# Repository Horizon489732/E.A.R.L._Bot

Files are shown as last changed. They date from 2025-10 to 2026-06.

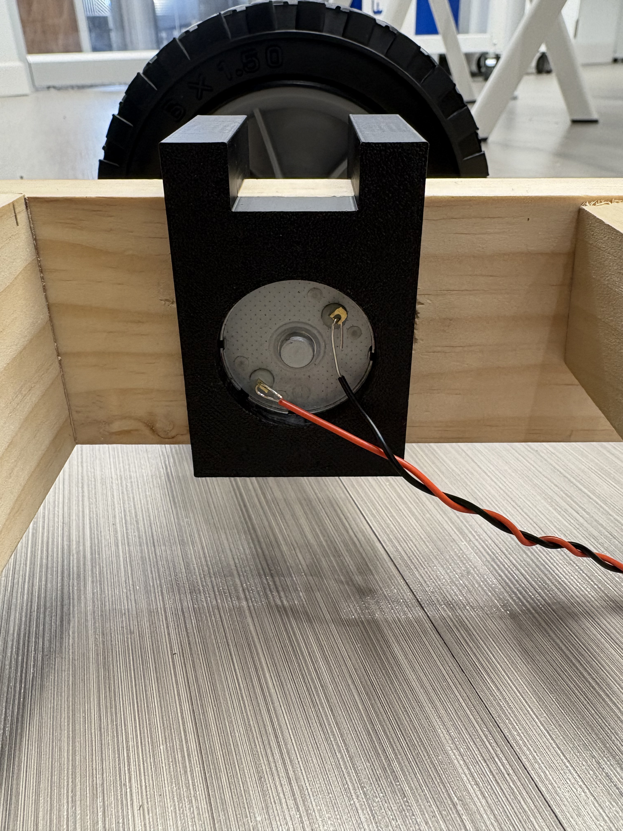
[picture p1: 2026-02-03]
Documentation/IMG_0114.jpeg

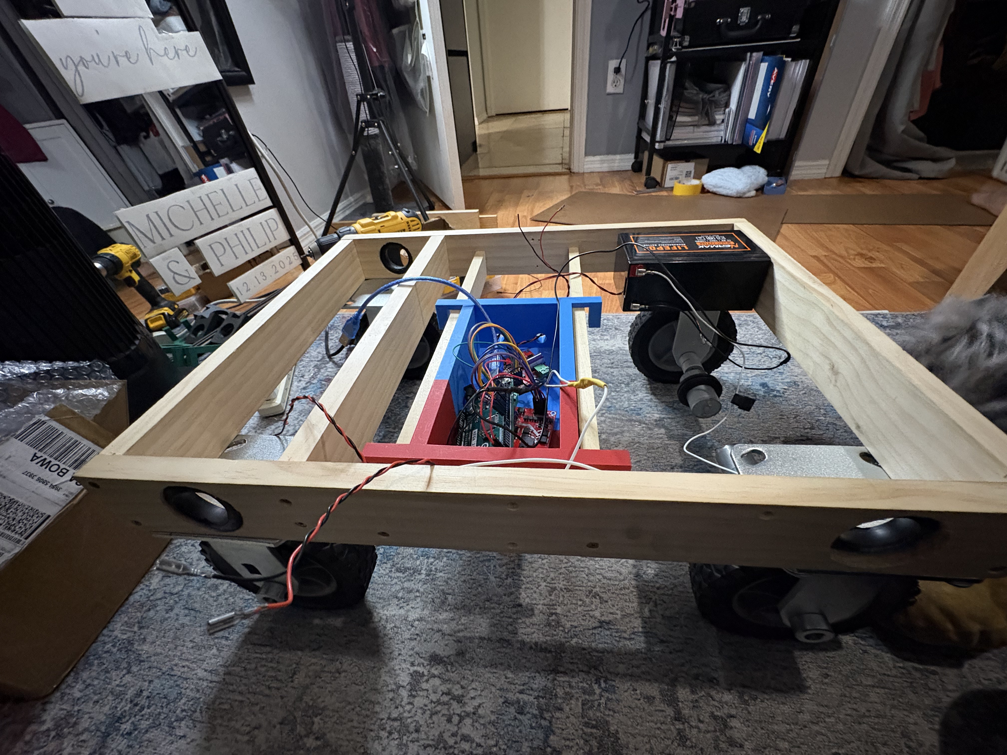
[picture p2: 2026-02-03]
Documentation/IMG_0233.jpeg

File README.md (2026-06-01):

# Everywhere-Anytime-Ready-for-Loading-BOT
- E.A.R.L. Bot will be a personal autonomous assistant ready to help you carry your items. E.A.R.L. Bot will be able to follow you around using tracking modules and sensors, helping students carry things around campus!

## Team Members & Roles
- Michelle Lee
- Daniel Jaffe
- Hien Tran
- Chris Nucci

Team EARL

## Demo

https://github.com/user-attachments/assets/fcbea098-207b-40ab-b3ea-2b303ecb1e78

## Object Detection

https://github.com/user-attachments/assets/0ccd8ff6-e306-4a9d-9102-31fed9cfe05f

## Technologies
- Microcontroller: An Arduino board will serve as the main processing unit, handling sensor data,
motor control, and communication with the tracking system.
- User Tracking: The robot will use RFID, Bluetooth Low Energy (BLE) beacons, or UltraWideband (UWB) technology to detect and follow a card or tag carried by the user. These technologies
allow accurate real-time positioning of the user even in busy environments.
- Receiver Modules: A corresponding RFID reader, BLE receiver, or UWB receiver on the robot
will process the signals from the user’s tag to determine distance and direction.
- Obstacle Detection and Avoidance: Ultrasonic sensors will scan the robot’s surroundings to detect
obstacles and navigate around them safely. Optional infrared (IR) sensors or LIDAR could be added
for higher accuracy in complex environments.
- Motion Control: Motor drivers will control the wheels, enabling smooth acceleration, deceleration,
and turning. Wheel encoders may be used for precise speed and distance measurement.
- Power Supply and Battery Management: A rechargeable battery will power the robot, and a
battery management system will ensure safe and efficient energy usage. 

## Goals
# Semester 1: Minimum Viable Product (MVP)
Autonomous User Tracking: Develop and implement a reliable sensor-based tracking system allowing the robot to seamlessly follow a designated target tag.

Payload Transport Capacity: Design and construct a rugged chassis capable of securely housing and transporting student items (such as backpacks and textbooks) across flat surfaces.

# Semester 2: Advanced Features & Refinement
Dynamic Obstacle Avoidance: Integrate ultrasonic sensors with real-time navigation algorithms to safely detect, slow down, and steer around obstacles or pedestrians in busy campus environments.

Aesthetics & Custom Branding: Complete the physical build by applying a clean paint job, enclosing the electronics safely, and mounting a custom, stylized E.A.R.L. signature sign to give the assistant a polished, professional look.

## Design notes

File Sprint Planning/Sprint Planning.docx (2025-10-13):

# E.A.R.L. Bot

E.A.R.L.

Chris Nucci, Daniel Jaffe, Hien Tran, Michelle Lee

GitHub repository:

Trello board: https://trello.com/b/Lrr7T9cK/earl-bot

# Sprint 1

Sprint Goal: Build E.A.R.L. Bot’s frame, mount the motors and wheels, and make the bot move back and forth.

Tasks:

Task | Team Member | Effort Estimation | Dependencies/Blockers | Task Breakdown
Design Frame | Michelle/ Hien/ Chris/ Daniel | 1 hour | NA | NA
Build Frame | Michelle | 1 hour | Wait till all parts for frame are attained. | NA
Mount Motors | Michelle | <1 hour | | NA
Mount/ Connect Wheels | Chris / Hien | 30 minutes | Frame needs to be done first | NA
Power Motors | Daniel / Hien | 1 hour | Motors need to be mounted with wheels first | NA
Program Arduino to Move in Sync | Daniel | 2 hours | NA | NA
Implement Power Switch | Daniel / Michelle | 1 hour | NA | NA

# Sprint 2

Sprint Goal: E.A.R.L. has a cargo hold and is able to do very simple tracking and following

Tasks Planned:

- Finish leftover tasks from Sprint 1
- Implement simple tracking
- Build Tag housing
- Build side rails for cargo area

# Sprint 3

Sprint Goal: E.A.R.L. is able to adjust speed based off distance to user.

Tasks Planned:

- Optimize distance and speed control
- Work out any bugs
- Aesthetic modifications

# Trello board

Entire Trello Board

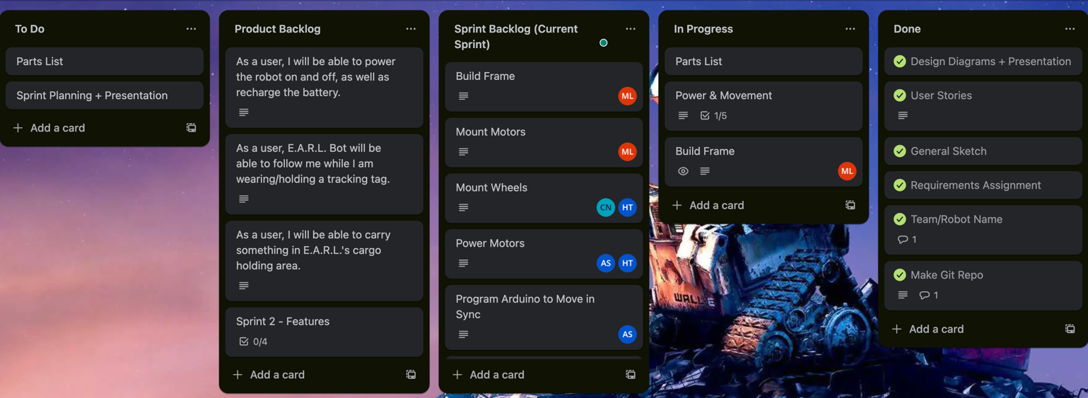
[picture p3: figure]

Product and Sprint Backlogs

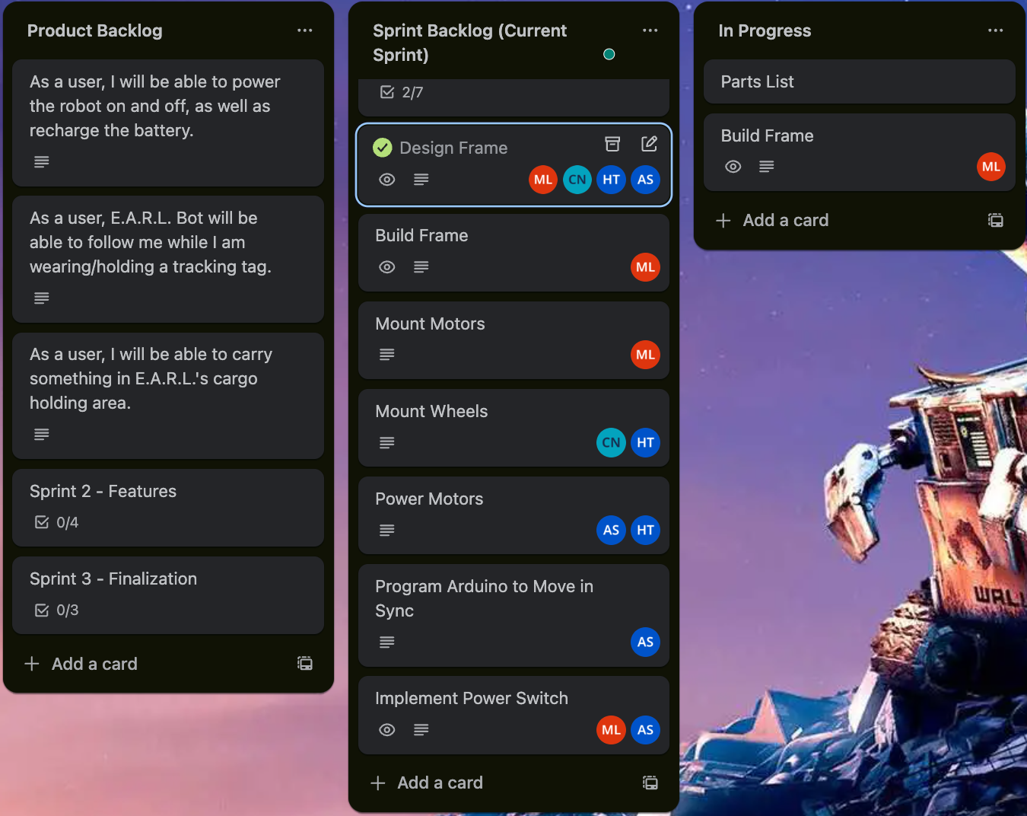
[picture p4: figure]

Close up of 1 task on Sprint Backlog – all other looks similar with their own times and dependencies

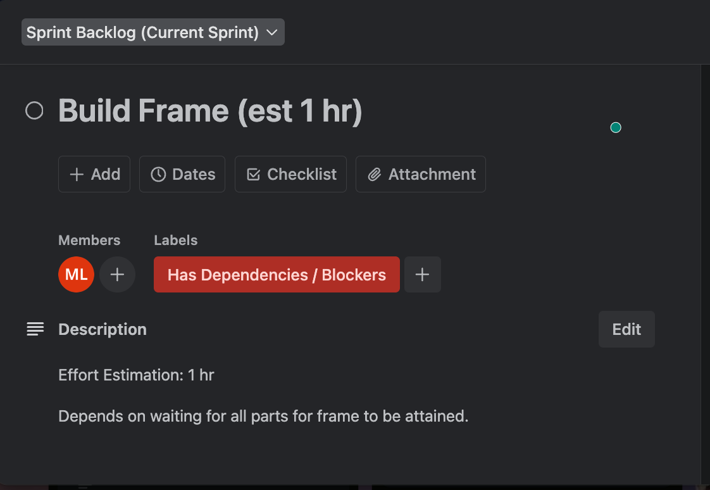
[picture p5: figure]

Senior Capstone I

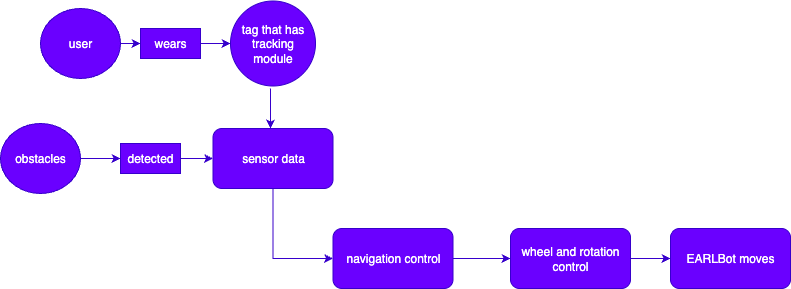
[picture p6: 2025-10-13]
Design Diagrams/Data_Flow_Diagram.png

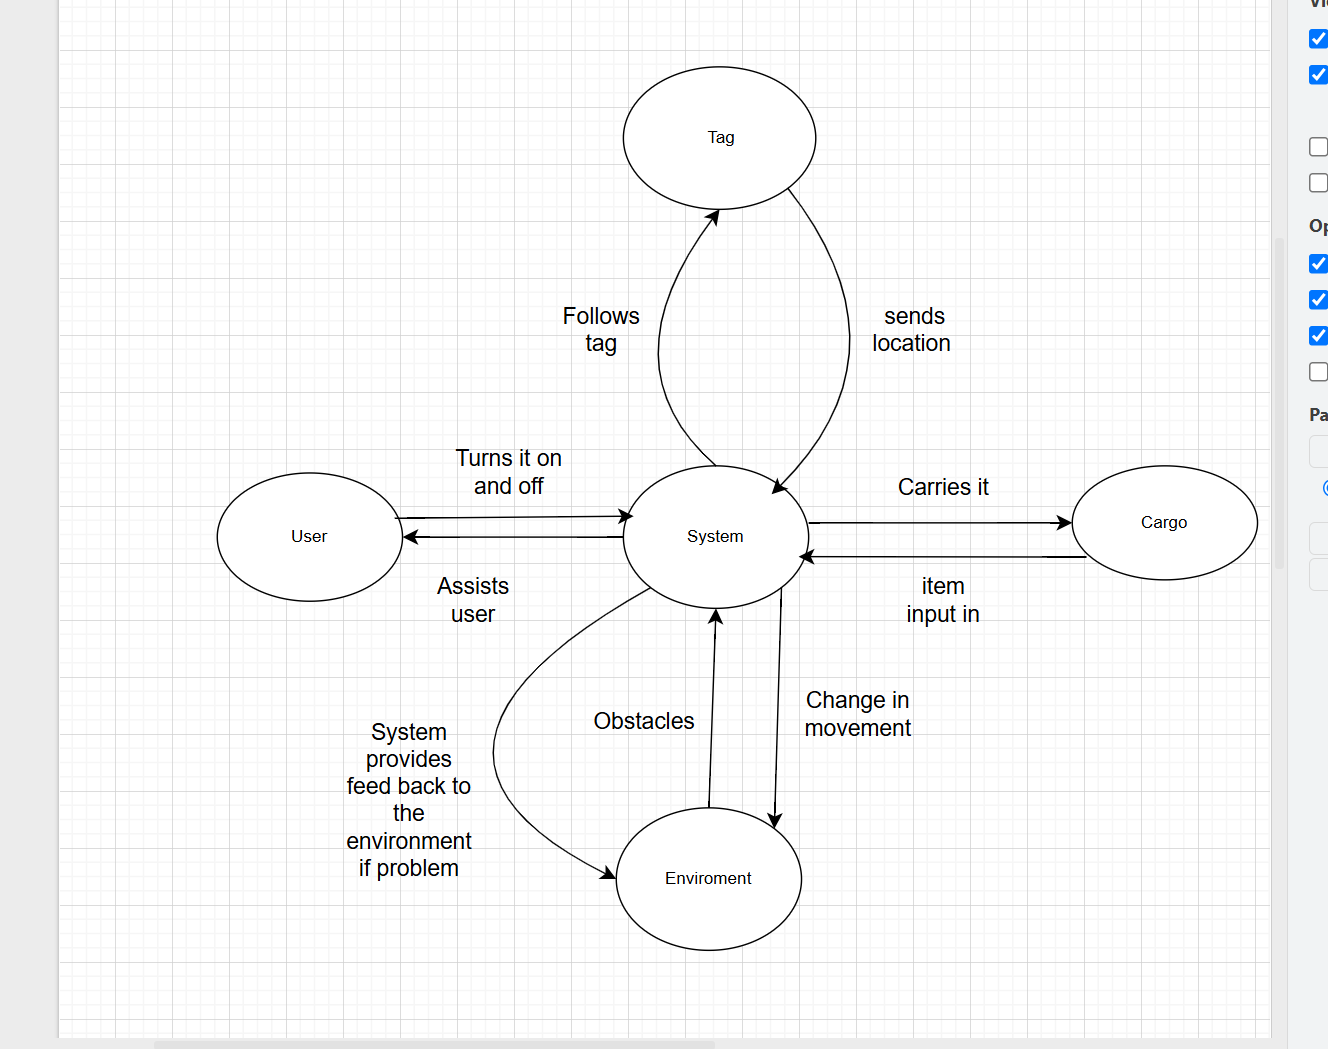
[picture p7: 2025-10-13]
Design Diagrams/context.png

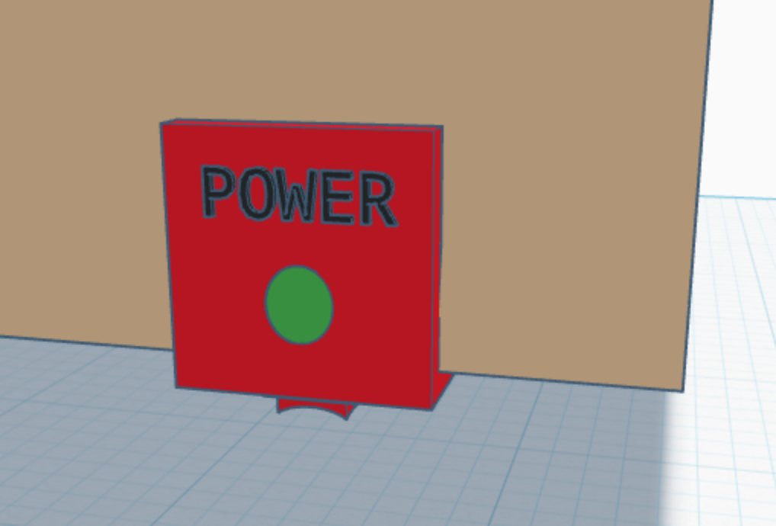
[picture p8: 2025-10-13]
Design Diagrams/UI Mockups/Screenshot 2025-10-05 at 12.27.10 AM.png

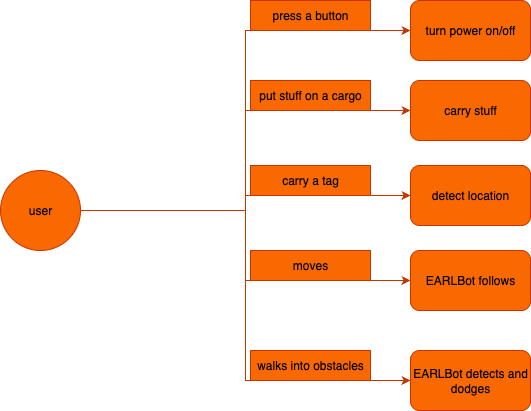
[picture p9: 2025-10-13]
Design Diagrams/Use_Case_Diagram.png

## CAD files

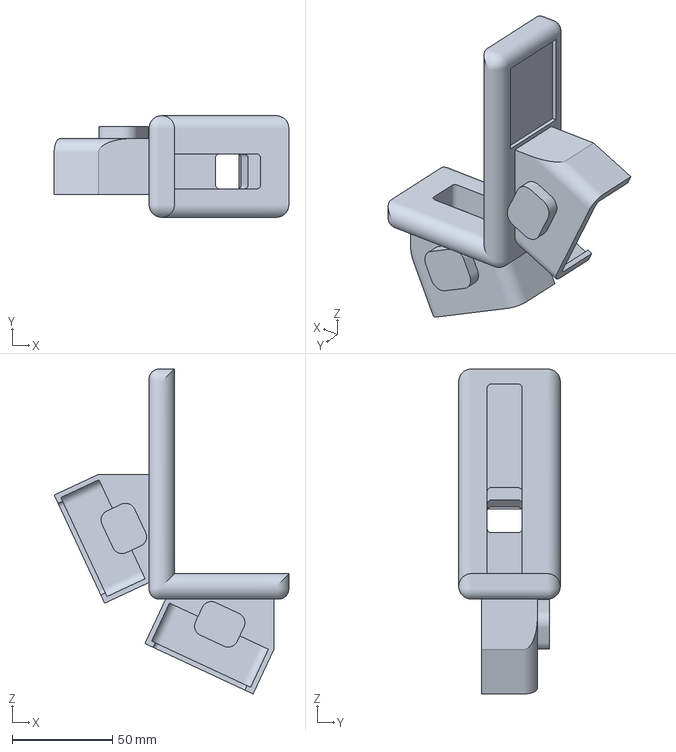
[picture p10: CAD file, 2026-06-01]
modeling Designs/assembly for ultrasonic sensors.3mf
117.3 x 50.8 x 162.4 mm

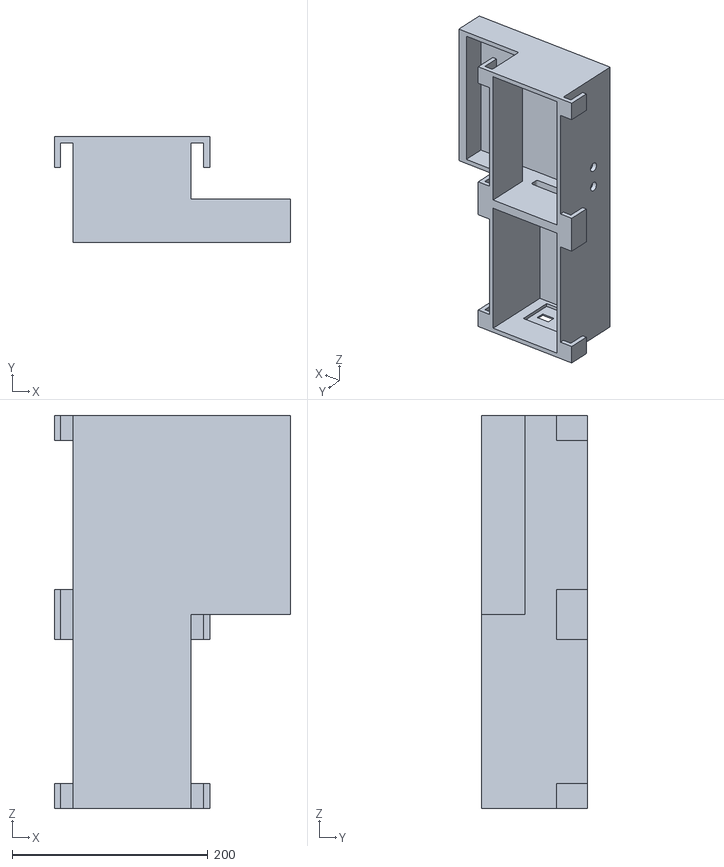
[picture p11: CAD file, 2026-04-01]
modeling Designs/basket for arduino.stl
241.3 x 107.9 x 401.3

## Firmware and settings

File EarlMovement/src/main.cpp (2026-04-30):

#include <Arduino.h>
#include <FastLED.h>

#define NUM_LEDS 7
#define DATA_PIN 13
#define BRIGHTNESS 255

CRGB leds[NUM_LEDS];

// Left Front Motor
int L_IN1 = 6;
int L_IN2 = 5;
int L_ENA = 7;

// Right Front Motor
int R_IN1 = 8;
int R_IN2 = 9;
int R_ENA = 10;

// Default speed (0–255)
int speed = 255;

int lastTimeReceived = 0;
int timeout = 5000;
// for distance reading
String incoming = "";

// for calculating connection timing
unsigned long startTime;
const int DATA_TIMEOUT_MS = 500;

// ===================== HC-SR04 SETUP =====================
// Current sensors (you already have these)
const int L_TRIG_PIN = 11;   // LEFT FRONT
const int L_ECHO_PIN = 12;

const int R_TRIG_PIN = 2;    // RIGHT FRONT
const int R_ECHO_PIN = 3;

// NEW sensors (CHANGE THESE PINS TO MATCH YOUR WIRING)
const int L2_TRIG_PIN = 47;   // LEFT SIDE (new)
const int L2_ECHO_PIN = 46;

const int R2_TRIG_PIN = 45;  // RIGHT SIDE (new)  <-- change if you want
const int R2_ECHO_PIN = 44;  // RIGHT SIDE (new)  <-- change if you want

float leftTiming = 0.0;
float leftDistanceCm = 0.0;
float rightTiming = 0.0;
float rightDistanceCm = 0.0;

float left2Timing = 0.0;
float left2DistanceCm = 0.0;
float right2Timing = 0.0;
float right2DistanceCm = 0.0;

// Anchor distances
struct AnchorDistances {
  int anchor1 = 0;
  int anchor2 = 0;
  int anchor3 = 0;
};

AnchorDistances dist;

// ===================== Avoidance settings/state =====================
const int AVOID_CM = 30;        // object avoidance threshold
const int DOORWAY_CM = 20;      // doorway override threshold

int avoidSide = 0;              // 0 = none, 1 = avoiding LEFT side, 2 = avoiding RIGHT side
int avoidSensor = 0;            // 1 = front sensor triggered, 2 = side sensor triggered
bool avoidPrinted = false;      // print message once when starting avoidance

// ===================== Helper: Stop all motors =====================
void stopMotors() {
  analogWrite(L_ENA, 0);
  analogWrite(R_ENA, 0);

  digitalWrite(R_IN1, LOW);
  digitalWrite(R_IN2, LOW);
  digitalWrite(L_IN1, LOW);
  digitalWrite(L_IN2, LOW);
}

// ===================== Move Forward =====================
void forward(int spd) {
  analogWrite(R_ENA, spd * 0.8);
  analogWrite(L_ENA, spd );

  digitalWrite(R_IN1, HIGH);
  digitalWrite(R_IN2, LOW);

  digitalWrite(L_IN1, HIGH);
  digitalWrite(L_IN2, LOW);
}

// ===================== Move Backward =====================
void backward(int spd) {
  analogWrite(R_ENA, spd);
  analogWrite(L_ENA, spd);

  digitalWrite(R_IN1, LOW);
  digitalWrite(R_IN2, HIGH);

  digitalWrite(L_IN1, LOW);
  digitalWrite(L_IN2, HIGH);
}

void moveAndTurnLeft2(int spd, int percentSpd) {
  analogWrite(R_ENA, spd);
  analogWrite(L_ENA, spd * (percentSpd / 100.0));

  digitalWrite(R_IN1, HIGH);
  digitalWrite(R_IN2, LOW);
  digitalWrite(L_IN1, HIGH);
  digitalWrite(L_IN2, LOW);
}

void moveAndTurnRight2(int spd, int percentSpd) {
  analogWrite(L_ENA, spd);
  analogWrite(R_ENA, spd * (percentSpd / 100.0));

  digitalWrite(R_IN1, HIGH);
  digitalWrite(R_IN2, LOW);
  digitalWrite(L_IN1, HIGH);
  digitalWrite(L_IN2, LOW);
}

// ===================== SERIAL PARSING =====================
void parseAnchorDistance(String line){
  int anchorID = 0;
  int anchorPos = line.indexOf("Anchor ");
  int dashPos   = line.indexOf(" -");
  if (anchorPos != -1 && dashPos != -1) {
      String idStr = line.substring(anchorPos + 7, dashPos);
      anchorID = idStr.toInt();
  }

  int colonIndex = line.indexOf(": ");
  int distance = 0;
  if (colonIndex != -1) {
      String distanceStr = line.substring(colonIndex + 2);
      int spaceIndex = distanceStr.indexOf(" ");
      if (spaceIndex != -1) {
          distanceStr = distanceStr.substring(0, spaceIndex);
      }
      distance = distanceStr.toInt();
  }

  switch(anchorID) {
      case 1: dist.anchor1 = distance; break;
      case 2: dist.anchor2 = distance; break;
      case 3: dist.anchor3 = distance; break;
  }
}

// ===================== Ultrasonic reads =====================

// LEFT FRONT
float readLeftUltrasonicCm() {
  digitalWrite(L_TRIG_PIN, LOW);
  delayMicroseconds(5);

  digitalWrite(L_TRIG_PIN, HIGH);
  delayMicroseconds(10);
  digitalWrite(L_TRIG_PIN, LOW);

  leftTiming = pulseIn(L_ECHO_PIN, HIGH, 30000);
  if (leftTiming == 0) return 0;
  return (leftTiming * 0.0344) / 2.0;
}

// RIGHT FRONT
float readRightUltrasonicCm() {
  digitalWrite(R_TRIG_PIN, LOW);
  delayMicroseconds(5);

  digitalWrite(R_TRIG_PIN, HIGH);
  delayMicroseconds(10);
  digitalWrite(R_TRIG_PIN, LOW);

  rightTiming = pulseIn(R_ECHO_PIN, HIGH, 30000);
  if (rightTiming == 0) return 0;
  return (rightTiming * 0.0344) / 2.0;
}

// LEFT SIDE (new)
float readLeft2UltrasonicCm() {
  digitalWrite(L2_TRIG_PIN, LOW);
  delayMicroseconds(5);

  digitalWrite(L2_TRIG_PIN, HIGH);
  delayMicroseconds(10);
  digitalWrite(L2_TRIG_PIN, LOW);

  left2Timing = pulseIn(L2_ECHO_PIN, HIGH, 30000);
  if (left2Timing == 0) return 0;
  return (left2Timing * 0.0344) / 2.0;
}

// RIGHT SIDE (new)
float readRight2UltrasonicCm() {
  digitalWrite(R2_TRIG_PIN, LOW);
  delayMicroseconds(5);

  digitalWrite(R2_TRIG_PIN, HIGH);
  delayMicroseconds(10);
  digitalWrite(R2_TRIG_PIN, LOW);

  right2Timing = pulseIn(R2_ECHO_PIN, HIGH, 30000);
  if (right2Timing == 0) return 0;
  return (right2Timing * 0.0344) / 2.0;
}

void calculateDirection() {

  // =============================
  // If we're already avoiding a side,
  // keep turning until BOTH sensors on that side are clear.
  // While doing this, ignore everything else.
  // =============================
  if (avoidSide == 1) { // avoiding LEFT side -> turn RIGHT
    bool leftBlocked = (leftDistanceCm > 0 && leftDistanceCm <= AVOID_CM);
    bool left2Blocked = (left2DistanceCm > 0 && left2DistanceCm <= AVOID_CM);

    if (leftBlocked || left2Blocked) {
      if (!avoidPrinted) {
        Serial.print("Avoiding LEFT side (trigger sensor ");
        Serial.print(avoidSensor);
        Serial.println(") -> turning RIGHT until clear");
        avoidPrinted = true;
      }
      moveAndTurnRight2(speed, 0);
      return;
    } else {
      Serial.println("LEFT side clear -> stopping avoidance");
      avoidSide = 0;
      avoidSensor = 0;
      avoidPrinted = false;
      // fall through to normal logic
    }
  }

  if (avoidSide == 2) { // avoiding RIGHT side -> turn LEFT
    bool rightBlocked = (rightDistanceCm > 0 && rightDistanceCm <= AVOID_CM);
    bool right2Blocked = (right2DistanceCm > 0 && right2DistanceCm <= AVOID_CM);

    if (rightBlocked || right2Blocked) {
      if (!avoidPrinted) {
        Serial.print("Avoiding RIGHT side (trigger sensor ");
        Serial.print(avoidSensor);
        Serial.println(") -> turning LEFT until clear");
        avoidPrinted = true;
      }
      moveAndTurnLeft2(speed, 20);
      return;
    } else {
      Serial.println("RIGHT side clear -> stopping avoidance");
      avoidSide = 0;
      avoidSensor = 0;
      avoidPrinted = false;
      // fall through to normal logic
    }
  }

  // =============================
  // 1️⃣ Check if tag disconnected
  // =============================
  if (dist.anchor1 == -1 || dist.anchor1 == 65535 ||
      dist.anchor2 == -1 || dist.anchor2 == 65535 ||
      dist.anchor3 == -1 || dist.anchor3 == 65535) {

    Serial.println("Stop Moving - tag disconnected");
    stopMotors();
    return;
  }

  // =============================
  // 2️⃣ Make sure anchors valid
  // =============================
  if (dist.anchor1 <= 30 || dist.anchor2 <= 30) {
    Serial.println("Invalid small reading");
    stopMotors();
    return;
  }

  // =============================
  // 3️⃣ Stop if too close
  // =============================
  if (dist.anchor1 < 175 || dist.anchor2 < 175) {
    Serial.println("Stopping Motors - too close");
    stopMotors();
    return;
  }

  // =============================
  // 4️⃣ Stop if too far
  // =============================
  if (dist.anchor1 > 1000 || dist.anchor2 > 1000) {
    Serial.println("Stopping Motors - too far");
    stopMotors();
    return;
  }


  // =============================
  // 4️⃣ Wrong direction check
  // =============================
  if (dist.anchor3 > dist.anchor1 && dist.anchor3 > dist.anchor2) {

    Serial.println("Wrong direction - pivot");

    if (dist.anchor1 > dist.anchor2) {
      Serial.println("Pivot Right");
      moveAndTurnRight2(speed, 0);
    } else {
      Serial.println("Pivot Left");
      moveAndTurnLeft2(speed, 0);
    }

    return;
  }

  // =============================
  // Doorway balancing override (front sensors only)
  // =============================
  if (leftDistanceCm > 0 && rightDistanceCm > 0 &&
      leftDistanceCm <= DOORWAY_CM && rightDistanceCm <= DOORWAY_CM) {

    Serial.println("Doorway balancing: BOTH <= 20cm -> going straight");
    forward(speed);
    return;
  }

  // =============================
  // NEW: Side avoidance start
  // If ONE sensor on a side sees something, start turning away.
  // Ignore the other sensor for "choosing" what to do (no flip-flopping),
  // but require BOTH sensors on that side to clear to stop turning.
  // =============================

  // LEFT side triggers -> start avoiding LEFT side (turn RIGHT)
  if (leftDistanceCm > 0 && leftDistanceCm <= AVOID_CM) {
    avoidSide = 1;
    avoidSensor = 1;   // front left triggered
    avoidPrinted = false;
    moveAndTurnRight2(speed, 0);
    return;
  }
  if (left2DistanceCm > 0 && left2DistanceCm <= AVOID_CM) {
    avoidSide = 1;
    avoidSensor = 2;   // side left triggered
    avoidPrinted = false;
    moveAndTurnRight2(speed, 0);
    return;
  }

  // RIGHT side triggers -> start avoiding RIGHT side (turn LEFT)
  if (rightDistanceCm > 0 && rightDistanceCm <= AVOID_CM) {
    avoidSide = 2;
    avoidSensor = 1;   // front right triggered
    avoidPrinted = false;
    moveAndTurnLeft2(speed, 0);
    return;
  }
  if (right2DistanceCm > 0 && right2DistanceCm <= AVOID_CM) {
    avoidSide = 2;
    avoidSensor = 2;   // side right triggered
    avoidPrinted = false;
    moveAndTurnLeft2(speed, 0);
    return;
  }

  // =============================
  // 5️⃣ Normal steering logic
  // =============================
  int diff = abs(dist.anchor1 - dist.anchor2);

  if (diff < 15) {
    Serial.println("Moving Forward");
    forward(speed);
  }
  else if (diff < 40) {
    Serial.println("Moderate Turn");

    if (dist.anchor1 > dist.anchor2) {
      moveAndTurnRight2(speed, 40);
    } else {
      moveAndTurnLeft2(speed, 70);
    }
  }
  else {
    Serial.println("Sharp Turn");

    if (dist.anchor1 > dist.anchor2) {
      moveAndTurnRight2(speed, 15);
    } else {
      moveAndTurnLeft2(speed, 30);
    }
  }
}

void setup() {
  pinMode(R_IN1, OUTPUT);
  pinMode(R_IN2, OUTPUT);
  pinMode(R_ENA, OUTPUT);

  pinMode(L_IN1, OUTPUT);
  pinMode(L_IN2, OUTPUT);
  pinMode(L_ENA, OUTPUT);

  // LEFT FRONT
  pinMode(L_TRIG_PIN, OUTPUT);
  pinMode(L_ECHO_PIN, INPUT);
  digitalWrite(L_TRIG_PIN, LOW);

  // RIGHT FRONT
  pinMode(R_TRIG_PIN, OUTPUT);
  pinMode(R_ECHO_PIN, INPUT);
  digitalWrite(R_TRIG_PIN, LOW);

  // LEFT SIDE (new)
  pinMode(L2_TRIG_PIN, OUTPUT);
  pinMode(L2_ECHO_PIN, INPUT);
  digitalWrite(L2_TRIG_PIN, LOW);

  // RIGHT SIDE (new)
  pinMode(R2_TRIG_PIN, OUTPUT);
  pinMode(R2_ECHO_PIN, INPUT);
  digitalWrite(R2_TRIG_PIN, LOW);

  Serial.begin(115200);
  Serial1.begin(9600);

  stopMotors();
  Serial.println("Motors ready!");

  FastLED.addLeds<NEOPIXEL, DATA_PIN>(leds, NUM_LEDS);
}

void loop() {
  fill_solid(leds, NUM_LEDS, CRGB(255, 105, 180));
  FastLED.show();
    
  // Read all ultrasonic distances
  leftDistanceCm = readLeftUltrasonicCm();
  rightDistanceCm = readRightUltrasonicCm();
  left2DistanceCm = readLeft2UltrasonicCm();
  right2DistanceCm = readRight2UltrasonicCm();

  // // prints <= 50 cm
  // if (rightDistanceCm > 0 && rightDistanceCm <= 50) {
  //   Serial.print("Right Front HC-SR04: ");
  //   Serial.print(rightDistanceCm);
  //   Serial.println(" cm");
  // }
  // if (leftDistanceCm > 0 && leftDistanceCm <= 50) {
  //   Serial.print("Left Front HC-SR04: ");
  //   Serial.print(leftDistanceCm);
  //   Serial.println(" cm");
  // }
  // if (left2DistanceCm > 0 && left2DistanceCm <= 50) {
  //   Serial.print("Left Side HC-SR04: ");
  //   Serial.print(left2DistanceCm);
  //   Serial.println(" cm");
  // }
  // if (right2DistanceCm > 0 && right2DistanceCm <= 50) {
  //   Serial.print("Right Side HC-SR04: ");
  //   Serial.print(right2DistanceCm);
  //   Serial.println(" cm");
  // }

  // If any data has arrived from the ESP32
  if (Serial1.available()) {
    startTime = millis();

    Serial.println("LAST TIME RECEIVED UPDATED: " + String(lastTimeReceived));
    String incomingLine = Serial1.readStringUntil('\n');

    parseAnchorDistance(incomingLine);
    Serial.print("Anchor1: "); Serial.println(dist.anchor1);
    Serial.print("Anchor2: "); Serial.println(dist.anchor2);
    Serial.print("Anchor3: "); Serial.println(dist.anchor3);

    calculateDirection();
  }

  // if no data is recieved from esp32 for half a second, stop motors 
  else {
    unsigned long elapsed = millis() - startTime;

    if (elapsed>DATA_TIMEOUT_MS) {
      Serial.println("No Data Received");
      stopMotors();
    }
  }


}

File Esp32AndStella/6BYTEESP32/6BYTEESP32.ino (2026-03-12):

#include <BLEDevice.h>
#include <BLEUtils.h>
#include <BLEScan.h>
#include <BLEClient.h>

#define SERVICE_UUID        "180C"
#define CHARACTERISTIC_UUID "2A56"

BLEAddress* tagAddress = nullptr;
bool doConnect = false;
bool connected = false;
BLEClient* pClient = nullptr;

// ===== Disconnect Handler =====
class MyClientCallback : public BLEClientCallbacks {
    void onConnect(BLEClient* pclient) {}
    void onDisconnect(BLEClient* pclient) {
        connected = false;
        Serial.println("Link Lost! Ready to re-scan...");
    }
};

// ===== Notification Handler =====
void notifyCallback(BLERemoteCharacteristic* pChar,
                    uint8_t* pData,
                    size_t length,
                    bool isNotify) {

    if (length != 6) return;

    uint16_t a1 = pData[0] | (pData[1] << 8);
    uint16_t a2 = pData[2] | (pData[3] << 8);
    uint16_t a3 = pData[4] | (pData[5] << 8);

    // ----- DEBUG (USB Serial) -----
    Serial.printf("Anchor 1 - Distance: %d mm\n", a1);
    Serial.printf("Anchor 2 - Distance: %d mm\n", a2);
    Serial.printf("Anchor 3 - Distance: %d mm\n", a3);

    // ----- SEND TO MOTOR ARDUINO -----
    Serial2.printf("Anchor 1 - Distance: %d mm\n", a1);
    Serial2.printf("Anchor 2 - Distance: %d mm\n", a2);
    Serial2.printf("Anchor 3 - Distance: %d mm\n", a3);
}


// ===== Scan Callback =====
class MyAdvertisedDeviceCallbacks: public BLEAdvertisedDeviceCallbacks {
    void onResult(BLEAdvertisedDevice advertisedDevice) {
        if (advertisedDevice.getName() == "BLE_SENDER") {
            Serial.println("Stella Found!");
            if (tagAddress != nullptr) delete tagAddress;
            tagAddress = new BLEAddress(advertisedDevice.getAddress());
            doConnect = true;
            BLEDevice::getScan()->stop(); // Stop scanning to connect
        }
    }
};

bool connectToTag() {
    Serial.println("Attempting connection...");
    pClient = BLEDevice::createClient();
    pClient->setClientCallbacks(new MyClientCallback());

    if (!pClient->connect(*tagAddress)) return false;

    BLERemoteService* pRemoteService = pClient->getService(BLEUUID(SERVICE_UUID));
    if (pRemoteService == nullptr) {
        pClient->disconnect();
        return false;
    }

    BLERemoteCharacteristic* pRemoteChar = pRemoteService->getCharacteristic(BLEUUID(CHARACTERISTIC_UUID));
    if (pRemoteChar == nullptr || !pRemoteChar->canNotify()) {
        pClient->disconnect();
        return false;
    }

    pRemoteChar->registerForNotify(notifyCallback);
    connected = true;
    return true;
}

void setup() {
    Serial.begin(115200);
    Serial2.begin(9600, SERIAL_8N1, 16, 17); // Adjust RX/TX pins for your specific ESP32
    
    BLEDevice::init("ESP32_RECEIVER");
    BLEScan* pBLEScan = BLEDevice::getScan();
    pBLEScan->setAdvertisedDeviceCallbacks(new MyAdvertisedDeviceCallbacks());
    pBLEScan->setActiveScan(true);
    Serial.println("Receiver Started. Scanning...");
}

void loop() {
    if (doConnect) {
        doConnect = false;
        if (connectToTag()) {
            Serial.println("Connected Successfully!");
        } else {
            
            Serial.println("Connection Failed.");
        }
    }

    if (!connected) {
        // This ensures the ESP32 keeps looking whenever it is offline
        Serial.println("The connection is disconnected");
                // ----- SEND TO MOTOR ARDUINO -----
        Serial2.printf("Anchor 1 - Distance: %d mm\n", -1);
        Serial2.printf("Anchor 2 - Distance: %d mm\n", -1);
        Serial2.printf("Anchor 3 - Distance: %d mm\n", -1);

        BLEDevice::getScan()->start(2, false); 
    }

    delay(500);
}

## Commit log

2025-11-05 Feat - added Arduino code to move foward and ability to change for futures changes at any speed
2025-11-06 Feat - added second motor drive to code
2025-11-20 Feat - change wiring and pin numbers
2026-01-20 feat - added stella to esp32 to arduino
2026-01-27 Rename IMG_0115.MOV to E.A.R.L. First Power Fail
2026-01-27 fix - fixed the esp32 bug now showing data make sure always on 9600 baud and added delay for testing in the arduino mega
    [main.cpp]
2026-01-27 no more zeros
    error protection against stella 0 values
    [main.cpp]
2026-02-05 Updated ESP32 and Tag code
2026-02-06 Fix - Fix arduino mega problem connecting to esp32 and made it if tag is disconnect stop motor and give error
    Fix - Fix arduino mage problem connecting to esp32
    [6BYTEESP32.ino, TagStellaBLEWORKS.ino, main.cpp]
2026-02-12 fix - organized calculate code and got it to run faster
    [main.cpp]
2026-02-24 smoother movement with ultrasonic sensors
2026-03-03 feat - uncommented esp32 code
2026-03-03 update - got rid of duplicate files in esp32 and arduino
2026-03-06 2 more ultrasonics and motor turning speed adjustments
2026-03-12 fix - now earl recieves -1 from esp32 when disconnect which stops motors
    [6BYTEESP32.ino, main.cpp]
2026-03-31 updated pivot avoidance right side
    [main.cpp]
2026-04-01 Create basket for arduino.stl
    [basket for arduino.stl]
2026-04-14 Added LED light
2026-04-30 fix - fixed the arduino code so that it stops when esp32 is no longer sending data
    [6BYTEESP32.ino, main.cpp]
2026-06-01 Feat - Added ultrasonic sensor assembly
    [assembly for ultrasonic sensors.3mf]
